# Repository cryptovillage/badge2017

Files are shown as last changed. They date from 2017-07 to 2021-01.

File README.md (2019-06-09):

# badge2017

To buld the ESP32 firmware:

1. Install the ESP32 toolchain for your OS. You do not need to install the ESP-IDF -- that happens automatically in the$
  * For Linux: https://esp-idf.readthedocs.io/en/v3.1-beta1/get-started/linux-setup.html
  * For Windows: https://esp-idf.readthedocs.io/en/v3.1-beta1/get-started/windows-setup.html
  * For OSX: https://esp-idf.readthedocs.io/en/v3.1-beta1/get-started/macos-setup.html

2. Pull in the ESP-IDF, MicroPython, and other dependencies:
`git submodule update --init --recursive`

3. Build mpy_cross:
`cd firmware/esp32/components/micropython/micropython/mpy-cross/ && make && cd ../../../..`

4. Optionally configure the serial port that your badge appears on (under Serial Flasher Config):
`make menuconfig`

5. Build it:
`make -j5`

6. Flash it:
`make flash` OR

`python esptool/esptool.py --chip esp32 --port /dev/ttyUSB0 --baud 115200 --before default_reset --after hard_reset write_flash -z --flash_mode dio --flash_freq 40m --flash_size detect 0x1000 bootloader.bin 0x10000 cpv2017.bin 0x8000 partitions.bin`

you may need to replace /dev/ttyUSB0 with /dev/ttyACM0 or whatever serial device the badge is listed as.

You can edit the build configuration with (includes wifi creds):

`make menuconfig`

SD Card contents can be found: https://2017.badge.cryptovillage.org/sdcard/0.3-prerel.zip

If your device is showing "TEST MODE", the EFM8 needs to be flashed. We've found that this only works from a Windows computer or Virtualbox with the Extension Pack for USB devices. If using a VM, we found that the IE11 Win7 testing VM from MicroSoft worked. You will need to install the driver from: https://www.silabs.com/products/development-tools/software/usb-to-uart-bridge-vcp-drivers

Download the flashing tools here: https://2017.badge.cryptovillage.org/W18779AXC7/TestFlash.zip

The prebuilt firmware can be found here: https://2017.badge.cryptovillage.org/firmware/v0.9/

You need to replace esp32test.bin with cpv2017.bin, and partitions_singleapp.bin with partitions.bin in TestFlash after unzipping. (Keeping the original filenames from TestFlash.zip contents but replacing the file content)

Hold down the knob when plugging the device in to put the device into a mode to flash the EFM8. The LEDs should not turn on and the screen will be blank and dim.

Run efm8load.exe to flash the EFM8. The device should reboot, but may require replugging in the USB cable. It should now appear as a serial device.

Then run NodeMCU-PyFlasher.exe to flash the ESP32.

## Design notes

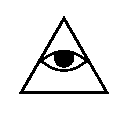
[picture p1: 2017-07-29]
assets/images/triangleeye.png

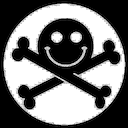
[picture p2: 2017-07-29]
assets/images/defcon.png

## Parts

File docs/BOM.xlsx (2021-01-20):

Item | Qty | Part Type | Reference | Manufacturer | Manufacturer P/N | Supplier | Supplier P/N | Description | Unit Price | Total | Link
1 | 1 | Rotary Encoder | SW1 | TT Electronics/BI | EN12-HS22AF20 | Digikey | 987-1195-ND | ENCODER 12MM ROTARY SW TOP ADJ | $0.67 | $0.67 | https://www.digikey.com/product-detail/en/tt-electronics-bi/EN12-HS22AF20/987-1195-ND/2408773
2 | 8 | LEDs | LED1,LED2,LED3,LED4,LED5,LED6,LED7,LED8 | Shenzhen Witop technology Company Co,.Ltd | APA-102-2020 |  |  | DOTSTAR MICRO LED APA102-2020 | $0.18 | $1.44 | https://www.digikey.com/products/en/optoelectronics/addressable-specialty/126?k=APA102%E2%80%932020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
3 | 1 | Screen |  | EastRising | ERC12864FS-1 | BuyDisplays.com | ERC12864FS-1 | 1.4 inch Graphic 128x64 LCD Module Serial SPI ST7565 Black on White | $2.84 | $2.84 | http://www.buydisplay.com/default/1-4-inch-graphic-128x64-lcd-module-serial-spi-st7565-black-on-white
4 | 1 | Screen connector | P5 | EastRising | ER-CON30HB-1 | BuyDisplays.com |  | 30 Pins 0.50mm Pitch ZIF Connector for Display | $0.16 | $0.16 | http://www.buydisplay.com/default/1-4-inch-graphic-128x64-lcd-module-serial-spi-st7565-black-on-white
5 | 1 | Screen connector | P6 | EastRising | ER-CON2.0-2P-SMD | BuyDisplays.com |  | 2 Pins 2.00mm Pitch Backlight Connector | $0.15 | $0.15 | http://www.buydisplay.com/default/1-4-inch-graphic-128x64-lcd-module-serial-spi-st7565-black-on-white
6 | 1 | LiPo Connector (2.00mm) | P3 | JST Sales America Inc. | S2B-PH-SM4-TB(LF)(SN) | Digikey | 455-1749-1-ND | 2 Positions Header, Shrouded Connector 0.079" (2.00mm) Surface Mount, Right Angle Tin | $0.42 | $0.42 | https://www.digikey.com/products/en?keywords=455-1749-1-ND
7 | 1 | LiPo |  |  |  |  |  | ~2300Mah |  | $0.00
8 | 1 | Micro USB Connector | P1 | Amphenol | 10118192-0001LF | Digikey | 609-4613-1-ND | USB - micro B USB 2.0 Receptacle Connector 5 Position Surface Mount, Right Angle, Horizontal | $0.27 | $0.27 | https://www.digikey.com/products/en?keywords=609-4613-1-ND
9 | 1 | ESP32 | U7 | Espressif | Espressif | Espressif | ESP-WROOM-32 | ESP32 module | $3.00 | $3.00 | https://espressif.com/en/products/hardware/esp32/overview
10 | 1 | MicroSD Holder | CON1 | Molex, LLC | 472192001 | Digikey | WM6698CT-ND | CONN MICRO SD CARD HINGED TYPE | $0.76 | $0.76 | https://www.digikey.com/product-detail/en/molex-llc/0472192001/WM6698CT-ND/3044147
11 | 1 | MicroSD Card |  |  |  |  |  | 4GB | $3.40 | $3.40 | https://www.aliexpress.com/item/Hot-sale-Memory-Cards-Micro-SD-Card-2GB-4GB-32GB-class-10-class-6-Microsd-TF/32700294360.html
12 | 1 | Resistor | R14 |  |  |  |  | 15 ohm, 10%, 1/10W, 0603 |  | $0.00
13 | 10 | Resistor | R1,R6,R9,R10,R11,R31,R41,R48,R49,R50 |  |  |  |  | 1k ohm, 5%, 0603 |  | $0.00
14 | 1 | Resistor | R8 |  |  |  |  | 1k87 ohm, 2%, 0603 |  | $0.00
15 | 1 | Resistor | R23 |  |  |  |  | 2k ohm, 5% 0603 |  | $0.00
16 | 1 | Resistor | R35 |  |  |  |  | 2k2 ohm, 5% 0603 |  | $0.00
17 | 2 | Resistor | R2,R3 |  |  |  |  | 4k7 ohm, 10%, 0603 |  | $0.00
18 | 1 | Resistor | R7 |  |  |  |  | 5k62 ohm, 2%, 0603 |  | $0.00
19 | 8 | Resistor | R21,R42,R43,R44,R45,R46,R47 |  |  |  |  | 10k ohm, 5%, 0603 |  | $0.00
20 | 1 | Resistor | R33 |  |  |  |  | 20k ohm, 5%, 0603 |  | $0.00
21 | 2 | Resistor | R27,R28 |  |  |  |  | 22k ohm, 5%, 0603 |  | $0.00
22 | 2 | Resistor | R29,R30 |  |  |  |  | 47k ohm, 5%, 0603 |  | $0.00
23 | 9 | Resistor | R4,R5,R13,R20,R22,R34,R37,R39,R40 |  |  |  |  | 100k ohm, 5%, 0603 |  | $0.00
24 | 1 | Resistor | R38 |  |  |  |  | 160k ohm, 5%, 0603 |  | $0.00
25 | 1 | Resistor | R36 |  |  |  |  | 200k ohm, 5%, 0603 |  | $0.00
26 | 1 | Resistor | R32 |  |  |  |  | 330k ohm, 5%, 0603 |  | $0.00
27 | 2 | Capacitor | C9,C10 |  |  |  |  | 12.5pF, +/-10%, 6.3V, 0603 |  | $0.00
28 | 1 | Capacitor | C48 |  |  |  |  | 47pF, +/- 10%, 6.3V, NP0/C0G, 0603 | 0.0098 | $0.01
29 | 1 | Capacitor | C46 |  |  |  |  | 0.01uF, +/- 10%, 6.3V, 0603 |  | $0.00
30 | 9 | Capacitor | C2,C8,C11,C16,C33,C34,C41,C42,C45 |  |  |  |  | 0.1uF, +/- 10%, 6.3V, NP0/COG, 0603 |  | $0.00
31 | 2 | Capacitor | C36,C37 |  |  |  |  | 0.47uF, +/- 10%, 6.3V, NP0/C0G, 0603 | 0.01372 | $0.03
32 | 21 | Capacitor | C6,C18,C19,C20,C21,C22,C23,C24,C25,C26,C27,C28,C29,C30,C31,C32,C38,C39,C40,C43,C44 |  |  |  |  | 1uF, +/- 20%, 25V, X5R/X7R, 0603 | 0.00796 | $0.17
33 | 5 | Capacitor | C1,C3,C4,C5,C35 |  |  |  |  | 4.7uF, +/- 20%, 16V, X5R/X7R, 0603 | 0.0266 | $0.13
34 | 5 | Capacitor | C7,C12,C13,C17,C47 |  |  |  |  | 10uF, +/- 20%, 16V, X5R/X7R, 0603 | 0.0404 | $0.20
35 | 2 | Capacitor | C14,C15 | Yageo |  |  |  | 22uF, +/- 20%, 10V, X5R/X7R, 0603 | 0.07176 | $0.14
36 | 1 | Resettable Fuse | F1 | Bourns Inc. | MF-USMF110-2 | Digikey | MF-USMF110-2CT-ND | 1100mA, 6V, 1210 | 0.2112 | $0.21
37 | 1 | Mic amp | U11 | Maxim Integrated | MAX4468EKA+T | Digikey | MAX4468EKA+CT-ND | IC PREAMP AUDIO MONO AB SOT23-8 | $0.51 | $0.51
38 | 1 | Headphone amp | U10 | Maxim Integrated | MAX9723DETE+ | Digikey | MAX9723DETE+-ND | IC AMP AUDIO .06W STER AB 16TQFN | $0.78 | $0.78
39 | 1 | Accelerometer | U9 | NXP | MMA8452QT | Digikey | MMA8452QT-ND | ACCELEROMETER 2-8G I2C 16QFN | $1.02 | $1.02
40 | 1 | switch | SW2 | C&K Components | JS202011SCQN | Digikey | 401-2002-1-ND | SWITCH SLIDE DPDT 300MA 6V | $0.36 | $0.36 | https://www.digikey.com/products/en?keywords=401-2002-1-ND
41 | 1 | crystal (32.768kHz) | Y1 | Abracon LLC | ABS25-32.768KHZ-T | Digikey | 535-9166-1-ND | CRYSTAL 32.7680KHZ 12.5PF SMD | $0.26 | $0.26 | https://www.digikey.com/product-detail/en/abracon-llc/ABS25-32.768KHZ-T/535-9166-1-ND/675683
42 | 2 | inductor | L1,L2 | Murata Electronics North America | LQM21PN4R7MGSD | Digikey | 490-12067-1-ND | 4.7 micro henry 750mA Inductor | $0.07 | $0.14 | http://www.digikey.com/product-detail/en/murata-electronics-north-america/LQM21PN4R7MGSD/490-12067-1-ND/5403080
43 | 2 | schottky diodes | D1,D2 | STMicroelectronics | BAT20JFILM | Digikey | 497-3381-1-ND | DIODE SCHOTTKY 23V 1A SOD323 | $0.21 | $0.41 | https://www.digikey.com/products/en?keywords=497-3381-1-ND
44 | 1 | microcontroller | U3 | Silicon Labs | EFM8UB10F16G-C-QFN28 | Digikey | 336-3409-5-ND | IC MCU 8BIT 16KB FLASH 28QFN | $1.22 | $1.22
45 | 1 | PMOS transistor | Q1 | Diodes Incorporated | DMG2307L-7 | Digikey | DMG2307L-7DICT-ND | MOSFET P-CH 30V 2.5A SOT-23 | $0.18 | $0.18
46 | 5 | NMOS transistor | Q2,Q3,Q4,Q5,Q6 | Fairchild/ON Semiconductor | MMBF170 | Digikey | MMBF170CT-ND | MOSFET N-CH 60V 500MA SOT-23 | $0.18 | $0.88 | https://www.digikey.com/products/en?keywords=DMG2307L-7DICT-ND
47 | 1 | Level Shifter | U8 | NXP USA Inc. | 74HCT245PW,118 | Digikey | 568-8174-1-ND | IC TRANSCVR TRI-ST 8BIT 20TSSOP | $0.25 | $0.25 | https://www.digikey.com/products/en?keywords=568-8174-1-ND
48 | 1 | ESD Protection Diode | U1 | Littelfuse Inc. | SP0503BAHTG | Digikey | F2715CT-ND | TVS DIODE 5.5VWM 8.5VC SOT143 | $0.59 | $0.59 | https://www.digikey.com/product-detail/en/littelfuse-inc/SP0503BAHTG/F2715CT-ND/1154322
49 | 1 | Battery Charger IC | U2 | Microchip | MCP73831T-2ACI/OT | Digikey | MCP73831T-2ACI/OTCT-ND | IC CONTROLLR LI-ION 4.2V SOT23-5 | $0.43 | $0.43 | https://www.digikey.com/products/en?keywords=MCP73831T-2ACI%2FOTCT-ND
50 | 1 | 3.3v Regulator | U6 | Diodes Incorporated | PAM2305AAB330 | Digikey | PAM2305AAB330DIDKR-ND | IC REG BUCK 3.3V 1A SYNC TSOT25 | $0.36 | $0.36 | https://www.digikey.com/products/en?keywords=PAM2301CAAB330DICT-ND
51 | 1 | 5v Regulator | U5 | Microchip Technology | MIC2288YD5-TR | Digikey | 576-1729-1-ND | IC REG BOOST ADJ 1.2A TSOT23-5 | $0.42 | $0.42 | https://www.digikey.com/product-detail/en/microchip-technology/MIC2288YD5-TR/576-1729-1-ND/1799425
52 | 1 | Crypto Chip | U4 | Atmel | ATECC508A-SSHDA-B | Digikey | ATECC508A-SSHDA-B-ND | IC EEPROM CRYPTO 10KB I2C 8SOIC | $0.66 | $0.66 | https://www.digikey.com/products/en?keywords=ATECC508A-SSHDA-B-ND
53 | 1 | TRRS 3.5mm jack | CON2 | CUI, Inc | SJ-43516-SMT-TR | Digikey | CP-43516SJCT-ND | 3.50mm (0.141", 1/8", Mini Plug) - Headphone Jack | $0.82 | $0.82 | http://www.digikey.com/product-detail/en/cui-inc/SJ-43516-SMT-TR/CP-43516SJCT-ND/669731
54 | 1 | PCB |  | PCBWay |  |  |  | 154.5mm x 95.1mm x 1.6mm, 2 Layers, 1 oz cu, Matte black soldermask, ENIG finish | $1.78 | $1.78
55 | 1 | Anti-static Bag | N/A | SCS | 10057 | Digikey | SCP390-ND | BAG 5X7" STATIC SHIELD 1=1EA | $0.10 | $0.10 | https://www.digikey.com/product-detail/en/scs/10057/SCP390-ND/3430431
56 | 1 | Lanyard | N/A | Custom Lanyards 4 All | N/A | Custom Lanyards 4 All |  | Polyester or Dye Sub? | $1.68 or $1.37 | $1.68 | https://www.customlanyards4all.com/
57 | 1 | Box | N/A |  |  | Alibaba |  | Black magnetic box (20cm x 14cm x 5cm) | $1.50 | $1.50
58 | 1 | USB Cable | N/A |  |  | Monoprice |  | USB 2.0 to Micro (black) | $0.61 | $0.61 | https://www.monoprice.com/product?c_id=103&cp_id=10303&cs_id=1030307&p_id=5137&seq=1&format=2
59 | 1 | Headphones | N/A | ??? | #04976961 | Light in the Box | N/A | N/A | $1.19 | $1.19 | http://www.lightinthebox.com/3-5mm-in-ear-headphones-headset-earphones-for-samsung-pc-cellphone_p4499380.html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
60 | 1 | Knob | N/A
61 | 1 | Instruction Sheet | N/A
 |  |  |  |  |  |  |  |  |  | $30.17

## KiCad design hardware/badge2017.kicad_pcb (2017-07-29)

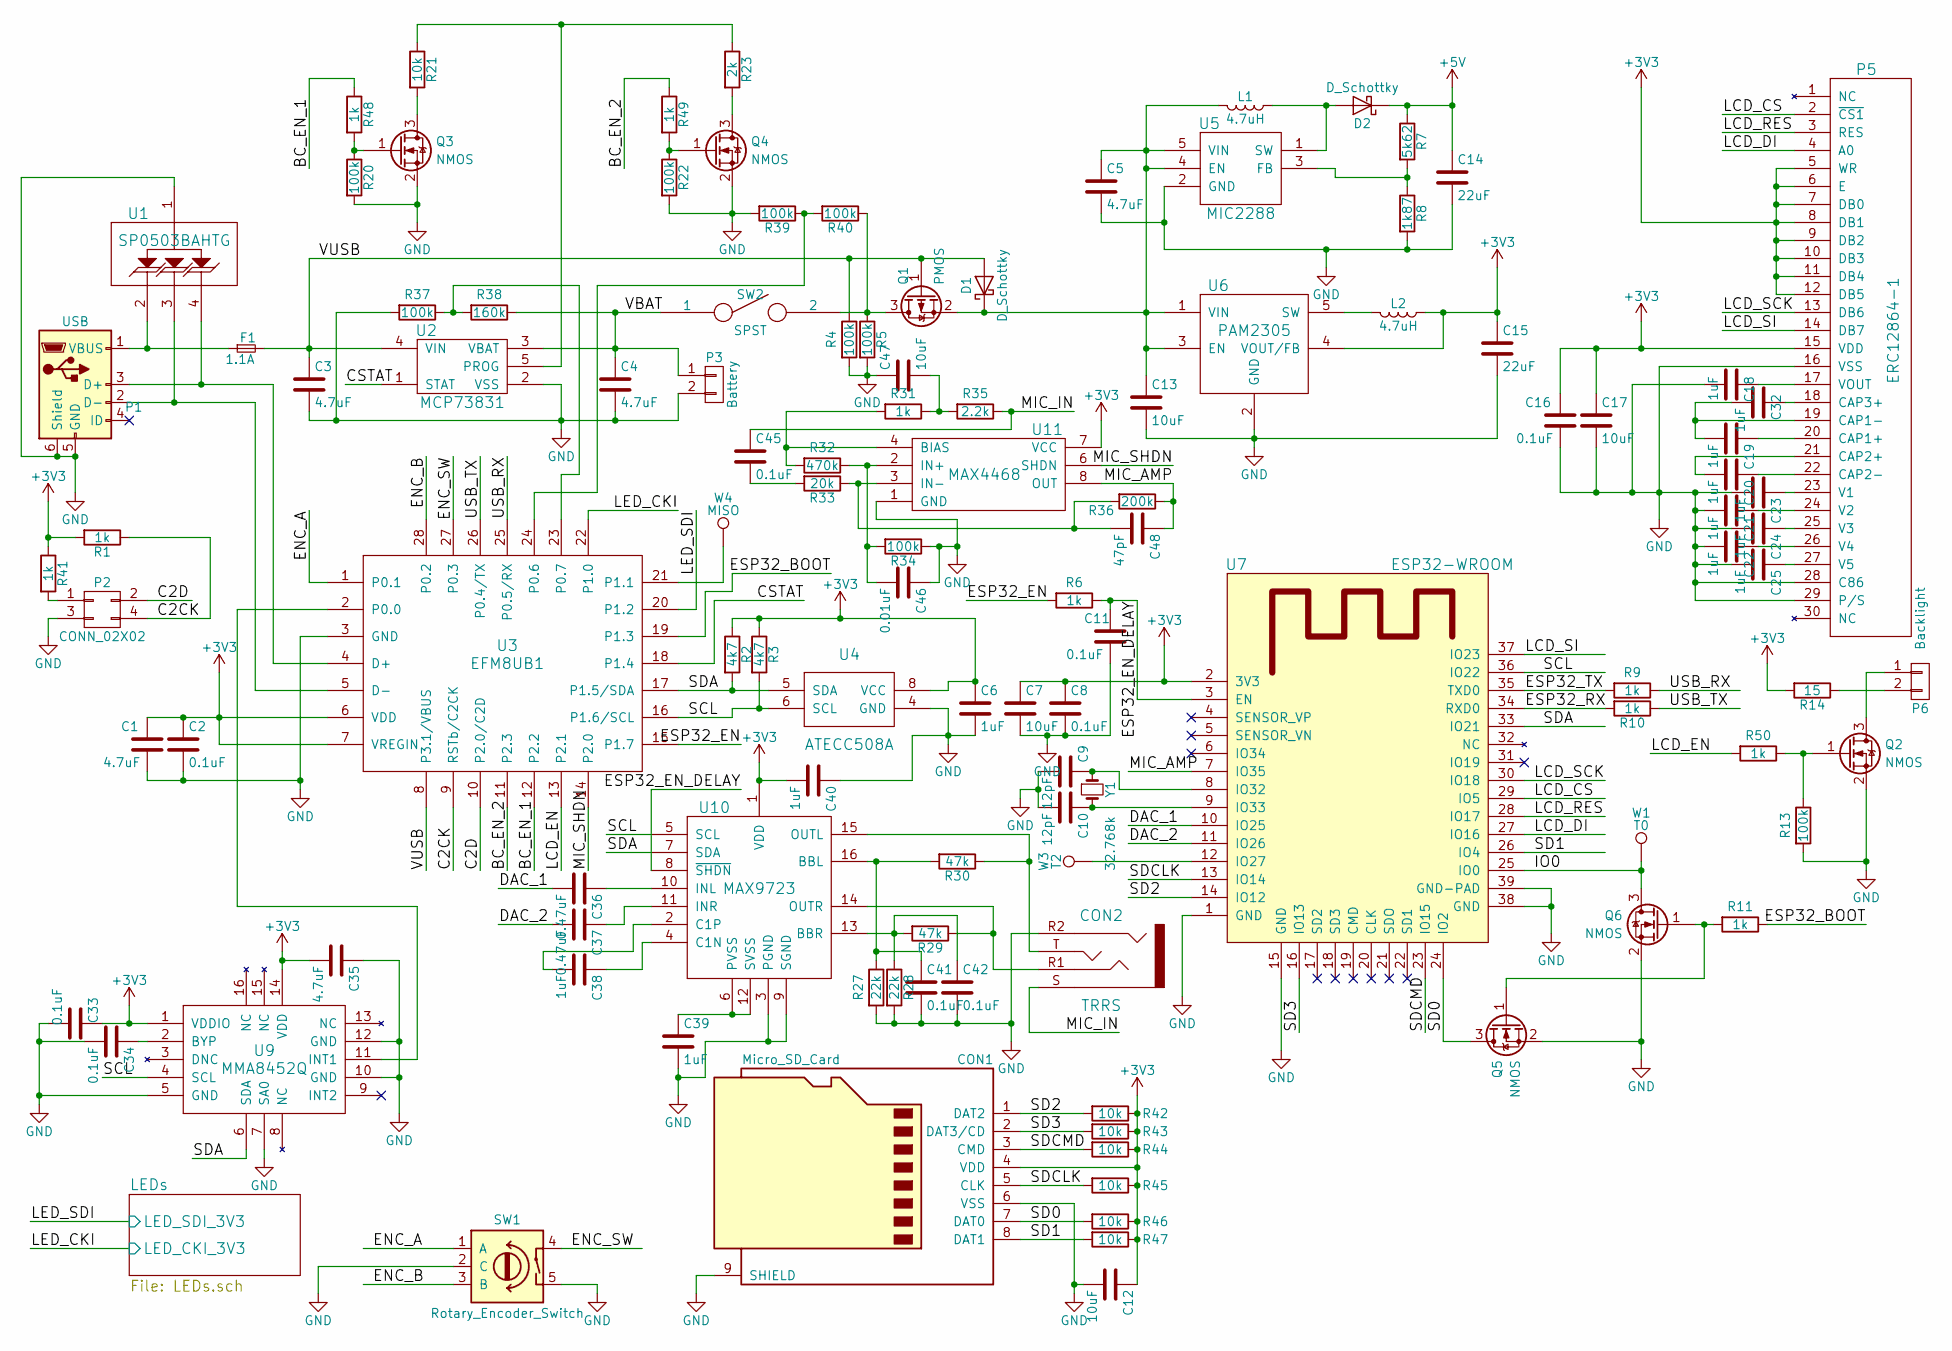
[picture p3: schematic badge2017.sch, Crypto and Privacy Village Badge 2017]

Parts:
C1, C35: 4.7uF; C_0603; Tolerance +/- 20%; Voltage 6.3V
C2, C8, C11, C16, C33, C34: 0.1uF; C_0603; Tolerance +/- 20%; Voltage 6.3V
C3, C4, C5: 4.7uF; C_0603; Tolerance +/- 20%; Voltage 16V
C6, C38, C40: 1uF; C_0603; Tolerance +/- 20%; Voltage 6.3V
C7, C12, C17, C47: 10uF; C_0603; Tolerance +/- 20%; Voltage 6.3V
C9, C10: 12pF; C_0603; Tolerance +/- 10%; Voltage 6.3V
C13: 10uF; C_0603; Tolerance +/- 20%; Voltage 16V
C14, C15: 22uF; C_0603; Tolerance +/- 20%; Voltage 10V
C18, C19, C20, C21, C22, C23, C24, C25, C32: 1uF; C_0603; Tolerance +/- 20%; Voltage 25V
C36, C37: 0.47uF; C_0603; Tolerance +/- 10%; Voltage 6.3V
C39: 1uF; C_0603; Tolerance +/- 20%; Voltage 16V
C41, C42, C45: 0.1uF; C_0603; Tolerance +/- 10%; Voltage 6.3V
C46: 0.01uF; C_0603; Tolerance +/- 10%; Voltage 6.3V
C48: 47pF; C_0603; Tolerance +/- 10%; Voltage 6.3V
CON1: Micro_SD_Card; MICROSD; MfgPartNum 472192001
CON2: TRRS; TRRS_jack; MfgPartNum SJ-43516-SMT-TR
D1, D2: D_Schottky; SOD-323; MfgPartNum BAT20JFILM
F1: 1.1A; R_1210; MfgPartNum MF-USMF110-2
L1, L2: 4.7uH; R_0603; MfgPartNum LQM21PN4R7MGSD
P1: USB; USB_Micro-B-cpv; MfgPartNum 10118192-0001LF
P2: CONN_02X02; Socket_Strip_Straight_2x02_TP
P3: Battery; JST_PH_SMD
P5: ERC12864-1; LCD_zif_connector
P6: Backlight; JST_PH_SMD
Q1: PMOS; SOT-23; MfgPartNum DMG2307L-7
Q2, Q3, Q4, Q5, Q6: NMOS; SOT-23; MfgPartNum MMBF170
R1, R6, R9, R10, R11, R41, R48, R49, R50: 1k; R_0603
R2, R3: 4k7; R_0603; Tolerance 0.1
R4, R5, R13, R20, R22: 100k; R_0603
R7: 5k62; R_0603; Tolerance 0.02
R8: 1k87; R_0603; Tolerance 0.02
R14: 15; R_0603; Tolerance 0.1
R21: 10k; R_0603; Tolerance 0.05
R23: 2k; R_0603; Tolerance 0.05
R27, R28: 22k; R_0603; Tolerance 0.05
R29, R30: 47k; R_0603; Tolerance 0.05
R31: 1k; R_0603; Tolerance 0.05
R32: 470k; R_0603; Tolerance 0.05
R33: 20k; R_0603; Tolerance 0.05
R34, R37, R39, R40: 100k; R_0603; Tolerance 0.05
R35: 2.2k; R_0603; Tolerance 0.05
R36: 200k; R_0603; Tolerance 0.05
R38: 160k; R_0603; Tolerance 0.05
R42, R43, R44, R45, R46, R47: 10k; R_0603
SW1: Rotary_Encoder_Switch; EN12_RotaryEncoder; MfgPartNum EN12-HS22AF20
SW2: SPST; DPDT_SMD; MfgPartNum JS202011SCQN
U1: SP0503BAHTG; SOT-143; MfgPartNum SP0503BAHTG
U2: MCP73831; SOT-23-5; MfgPartNum MCP73831T-2ACI/OT
U3: EFM8UB1; QFN-28-1EP_5x5mm_Pitch0.5mm; MfgPartNum EFM8UB10F16G-C-QFN28
U4: ATECC508A; SOIC-8_3.9x4.9mm_Pitch1.27mm; MfgPartNum ATECC508A-SSHDA-B
U5: MIC2288; SOT-23-5; MfgPartNum MIC2288YD5-TR
U6: PAM2305; SOT-23-5; MfgPartNum PAM2305AAB330
U7: ESP32-WROOM; MfgPartNum ESP-WROOM-32
U9: MMA8452Q; MfgPartNum MMA8452QT
U10: MAX9723; QFN-16-1EP_4x4mm_Pitch0.65mm; MfgPartNum MAX9723DETE+
U11: MAX4468; SOT-23-8; MfgPartNum MAX4468EKA+T
W1: T0; Measurement_Point_Round-SMD-Pad_Small
W3: T2; Measurement_Point_Round-SMD-Pad_Small
W4: MISO; Measurement_Point_Round-SMD-Pad_Small
Y1: 32.768k; abs25_crystal; MfgPartNum ABS25-32.768KHZ-T

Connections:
+3V3: C1.1, C2.1, C6.1, C7.1, C8.1, C12.1, C15.1, C16.1, C17.1, C33.1, C35.2, C40.2, CON1.4 (VDD), L2.1, P5.5 (WR), P5.6 (E), P5.7 (DB0), P5.8 (DB1), P5.9 (DB2), P5.10 (DB3), P5.11 (DB4), P5.12 (DB5), P5.15 (VDD), R1.2, R2.1, R3.1, R14.2, R41.1, R42.1, R43.1, R44.1, R45.1, R46.1, R47.1, U3.6 (VDD), U3.7 (VREGIN), U4.8 (VCC), U6.4 (VOUT/FB), U7.2 (3V3), U9.1 (VDDIO), U9.14 (VDD), U10.1 (VDD), U11.7 (VCC)
+5V: C14.1, D2.1 (K), R7.1; also elsewhere on the board
/BC_EN_1: R48.1, U3.12 (P2.2)
/BC_EN_2: R49.1, U3.11 (P2.3)
/C2CK: P2.4, R1.1, U3.9 (RSTb/C2CK)
/C2D: P2.2, U3.10 (P2.0/C2D)
/CSTAT: U2.1 (STAT), U3.18 (P1.4)
/DAC_1: C36.2, U7.10 (IO25)
/DAC_2: C37.2, U7.11 (IO26)
/ENC_A: SW1.1 (A), U3.1 (P0.1)
/ENC_B: SW1.3 (B), U3.28 (P0.2)
/ENC_SW: SW1.4, U3.27 (P0.3)
/ESP32_BOOT: R11.1, U3.19 (P1.3)
/ESP32_EN: R6.2, U3.15 (P1.7)
/ESP32_EN_DELAY: C11.1, R6.1, U7.3 (EN), U10.8 (~SHDN)
/ESP32_RX: R10.2, U7.34 (RXD0)
/ESP32_TX: R9.2, U7.35 (TXD0)
/IO0: Q6.3 (D), U7.25 (IO0), W1.1
/LCD_CS: P5.2 (~CS1), U7.29 (IO5)
/LCD_DI: P5.4 (A0), U7.27 (IO16)
/LCD_EN: R50.2, U3.13 (P2.1)
/LCD_RES: P5.3 (RES), U7.28 (IO17)
/LCD_SCK: P5.13 (DB6), U7.30 (IO18)
/LCD_SI: P5.14 (DB7), U7.37 (IO23)
/LED_CKI: U3.22 (P1.0); also elsewhere on the board
/LED_SDI: U3.20 (P1.2); also elsewhere on the board
/MIC_AMP: C48.1, R36.1, U7.7 (IO35), U11.8 (OUT)
/MIC_IN: C45.1, CON2.S, R35.1
/MIC_SHDN: U3.14 (P2.0), U11.6 (SHDN)
/SCL: R3.2, U3.16 (P1.6/SCL), U4.6 (SCL), U7.36 (IO22), U9.4 (SCL), U10.5 (SCL)
/SD0: CON1.7 (DAT0), Q5.3 (D), R46.2, U7.24 (IO2)
/SD1: CON1.8 (DAT1), R47.2, U7.26 (IO4)
/SD2: CON1.1 (DAT2), R42.2, U7.14 (IO12)
/SD3: CON1.2 (DAT3/CD), R43.2, U7.16 (IO13)
/SDA: R2.2, U3.17 (P1.5/SDA), U4.5 (SDA), U7.33 (IO21), U9.6 (SDA), U10.7 (SDA)
/SDCLK: CON1.5 (CLK), R45.2, U7.13 (IO14)
/SDCMD: CON1.3 (CMD), R44.2, U7.23 (IO15)
/USB_RX: R9.1, U3.25 (P0.5/RX)
/USB_TX: R10.1, U3.26 (P0.4/TX)
/VBAT: C4.1, P3.1, R38.1, SW2.1, U2.3 (VBAT)
/VUSB: C3.1, D1.2 (A), F1.2, Q1.1 (G), R4.1, U2.4 (VIN), U3.8 (P3.1/VBUS)
GND: C1.2, C2.2, C3.2, C4.2, C5.2, C6.2, C7.2, C8.2, C9.2, C10.2, C11.2, C12.2, C13.2, C14.2, C15.2, C16.2, C17.2, C18.2, C21.2, C22.2, C23.2, C24.2, C25.2, C33.2, C34.2, C35.1, C39.2, C40.1, C41.2, C42.2, C46.1, C47.1, CON1.6 (VSS), CON1.9 (SHIELD), CON2.R2, P1.5 (GND), P1.6 (Shield), P2.3, P3.2, P5.16 (VSS), P5.28 (C86), P5.29 (P/S), Q2.2 (S), Q3.2 (S), Q4.2 (S), Q5.2 (S), Q6.2 (S), R4.2, R5.2, R8.2, R13.2, R20.2, R22.2, R27.2, R28.2, R34.1, R37.2, R39.2, SW1.2 (C), SW1.5, U1.1, U2.2 (VSS), U3.3 (GND), U4.4 (GND), U5.2 (GND), U6.2 (GND), U7.1 (GND), U7.15 (GND), U7.38 (GND), U7.39 (GND-PAD), U9.5 (GND), U9.7 (SA0), U9.10 (GND), U9.12 (GND), U10.3 (PGND), U10.9 (SGND), U11.1 (GND); also elsewhere on the board
unnamed: C9.1, U7.8 (IO32), Y1.1
unnamed: C10.1, U7.9 (IO33), Y1.2
unnamed: C5.1, C13.1, D1.1 (K), L1.2, Q1.2 (S), U5.4 (EN), U5.5 (VIN), U6.1 (VIN), U6.3 (EN)
unnamed: C18.1, P5.17 (VOUT)
unnamed: C19.1, P5.20 (CAP1+)
unnamed: C19.2, C32.2, P5.19 (CAP1-)
unnamed: C20.1, P5.22 (CAP2-)
unnamed: C20.2, P5.21 (CAP2+)
unnamed: C21.1, P5.24 (V2)
unnamed: C22.1, P5.26 (V4)
unnamed: C23.1, P5.23 (V1)
unnamed: C24.1, P5.25 (V3)
unnamed: C25.1, P5.27 (V5)
unnamed: C32.1, P5.18 (CAP3+)
unnamed: C34.1, U9.2 (BYP)
unnamed: C36.1, U10.10 (INL)
unnamed: C37.1, U10.11 (INR)
unnamed: C38.1, U10.4 (C1N)
unnamed: C38.2, U10.2 (C1P)
unnamed: C39.1, U10.6 (PVSS), U10.12 (SVSS)
unnamed: C41.1, R27.1, R30.2, U10.16 (BBL)
unnamed: C42.1, R28.1, R29.2, U10.13 (BBR)
unnamed: C45.2, R33.2
unnamed: C46.2, R32.1, R34.2, U11.2 (IN+)
unnamed: C47.2, R31.1, R35.2
unnamed: C48.2, R33.1, R36.2, U11.3 (IN-)
unnamed: CON2.R1, R29.1, U10.14 (OUTR)
unnamed: CON2.T, R30.1, U10.15 (OUTL)
unnamed: D2.2 (A), L1.1, U5.1 (SW)
unnamed: F1.1, P1.1 (VBUS), U1.2
unnamed: L2.2, U6.5 (SW)
unnamed: P1.2 (D-), U1.3, U3.5 (D-)
unnamed: P1.3 (D+), U1.4, U3.4 (D+)
unnamed: P2.1, R41.2
unnamed: P6.1, Q2.3 (D)
unnamed: P6.2, R14.1
unnamed: Q1.3 (D), R5.1, R40.1, SW2.2
unnamed: Q2.1 (G), R13.1, R50.1
unnamed: Q3.1 (G), R20.1, R48.2
unnamed: Q3.3 (D), R21.2
unnamed: Q4.1 (G), R22.1, R49.2
unnamed: Q4.3 (D), R23.2
unnamed: Q5.1 (G), Q6.1 (G), R11.2
unnamed: R7.2, R8.1, U5.3 (FB)
unnamed: R21.1, R23.1, U2.5 (PROG)
unnamed: R31.2, R32.2, U11.4 (BIAS)
unnamed: R37.1, R38.2, U3.23 (P0.7)
unnamed: R39.1, R40.2, U3.24 (P0.6)
unnamed: U3.2 (P0.0), U9.11 (INT1)
unnamed: U3.21 (P1.1), W4.1
unnamed: U7.12 (IO27), W3.1

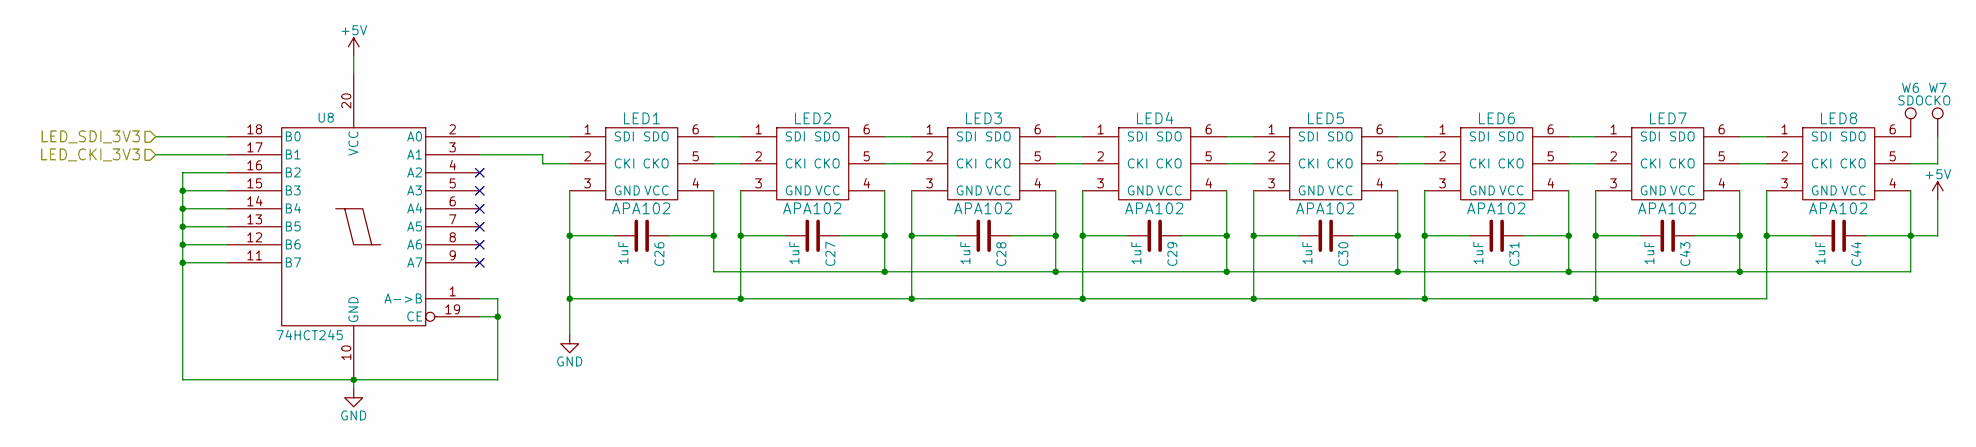
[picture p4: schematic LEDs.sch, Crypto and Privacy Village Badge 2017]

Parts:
C26, C27, C28, C29, C30, C31, C43, C44: 1uF; C_0603; Voltage 16V
LED1, LED2, LED3, LED4, LED5, LED6, LED7, LED8: APA102; APA102-2020
U8: 74HCT245; TSSOP-20_4.4x6.5mm_Pitch0.65mm; MfgPartNum 74HCT245PW,118
W6: SDO; Measurement_Point_Round-SMD-Pad_Small
W7: CKO; Measurement_Point_Round-SMD-Pad_Small

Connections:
+5V: C26.1, C27.1, C28.1, C29.1, C30.1, C31.1, C43.1, C44.1, LED1.4 (VCC), LED2.4 (VCC), LED3.4 (VCC), LED4.4 (VCC), LED5.4 (VCC), LED6.4 (VCC), LED7.4 (VCC), LED8.4 (VCC), U8.20 (VCC); also elsewhere on the board
/LED_CKI: U8.17 (B1); also elsewhere on the board
/LED_SDI: U8.18 (B0); also elsewhere on the board
GND: C26.2, C27.2, C28.2, C29.2, C30.2, C31.2, C43.2, C44.2, LED1.3 (GND), LED2.3 (GND), LED3.3 (GND), LED4.3 (GND), LED5.3 (GND), LED6.3 (GND), LED7.3 (GND), LED8.3 (GND), U8.1 (A->B), U8.10 (GND), U8.11 (B7), U8.12 (B6), U8.13 (B5), U8.14 (B4), U8.15 (B3), U8.16 (B2), U8.19 (CE); also elsewhere on the board
unnamed: LED1.1 (SDI), U8.2 (A0)
unnamed: LED1.2 (CKI), U8.3 (A1)
unnamed: LED1.5 (CKO), LED2.2 (CKI)
unnamed: LED1.6 (SDO), LED2.1 (SDI)
unnamed: LED2.5 (CKO), LED3.2 (CKI)
unnamed: LED2.6 (SDO), LED3.1 (SDI)
unnamed: LED3.5 (CKO), LED4.2 (CKI)
unnamed: LED3.6 (SDO), LED4.1 (SDI)
unnamed: LED4.5 (CKO), LED5.2 (CKI)
unnamed: LED4.6 (SDO), LED5.1 (SDI)
unnamed: LED5.5 (CKO), LED6.2 (CKI)
unnamed: LED5.6 (SDO), LED6.1 (SDI)
unnamed: LED6.5 (CKO), LED7.2 (CKI)
unnamed: LED6.6 (SDO), LED7.1 (SDI)
unnamed: LED7.5 (CKO), LED8.2 (CKI)
unnamed: LED7.6 (SDO), LED8.1 (SDI)
unnamed: LED8.5 (CKO), W7.1
unnamed: LED8.6 (SDO), W6.1

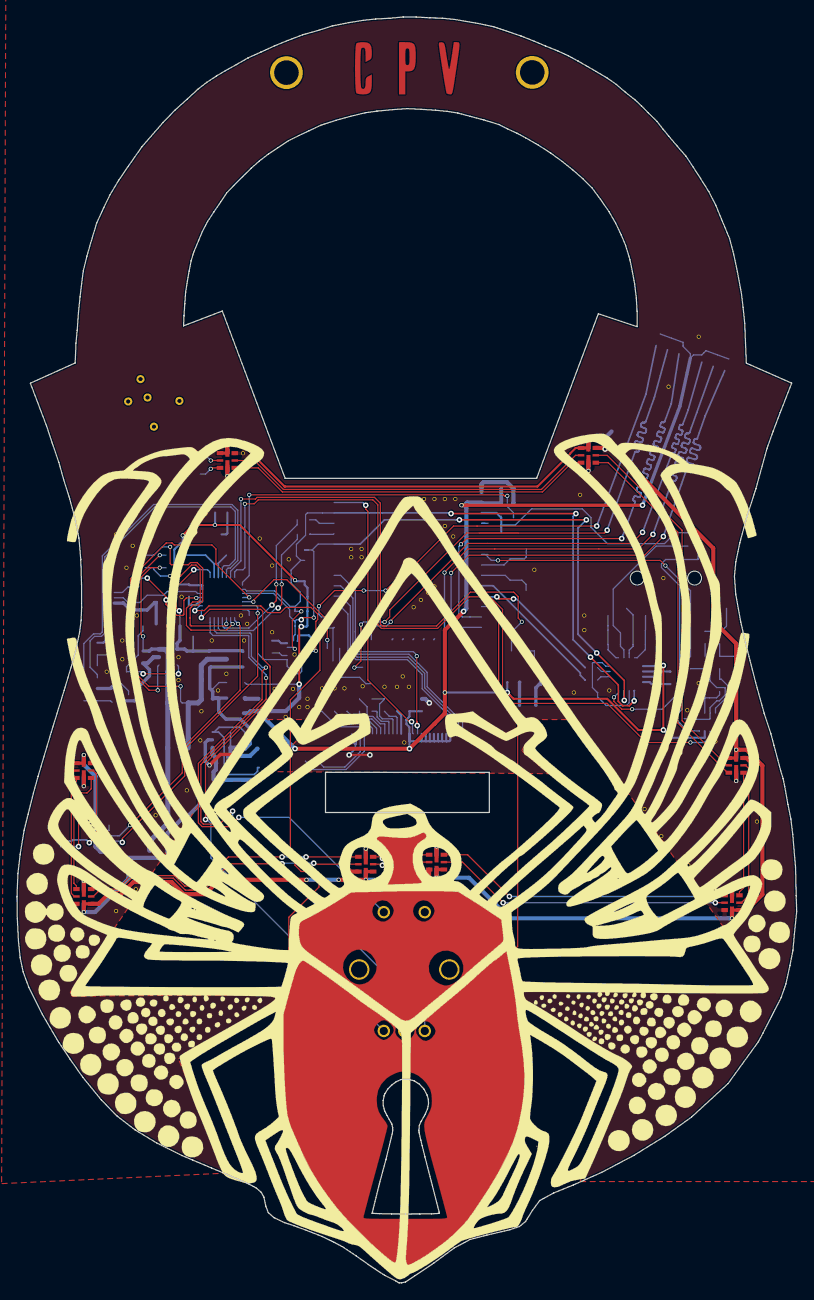
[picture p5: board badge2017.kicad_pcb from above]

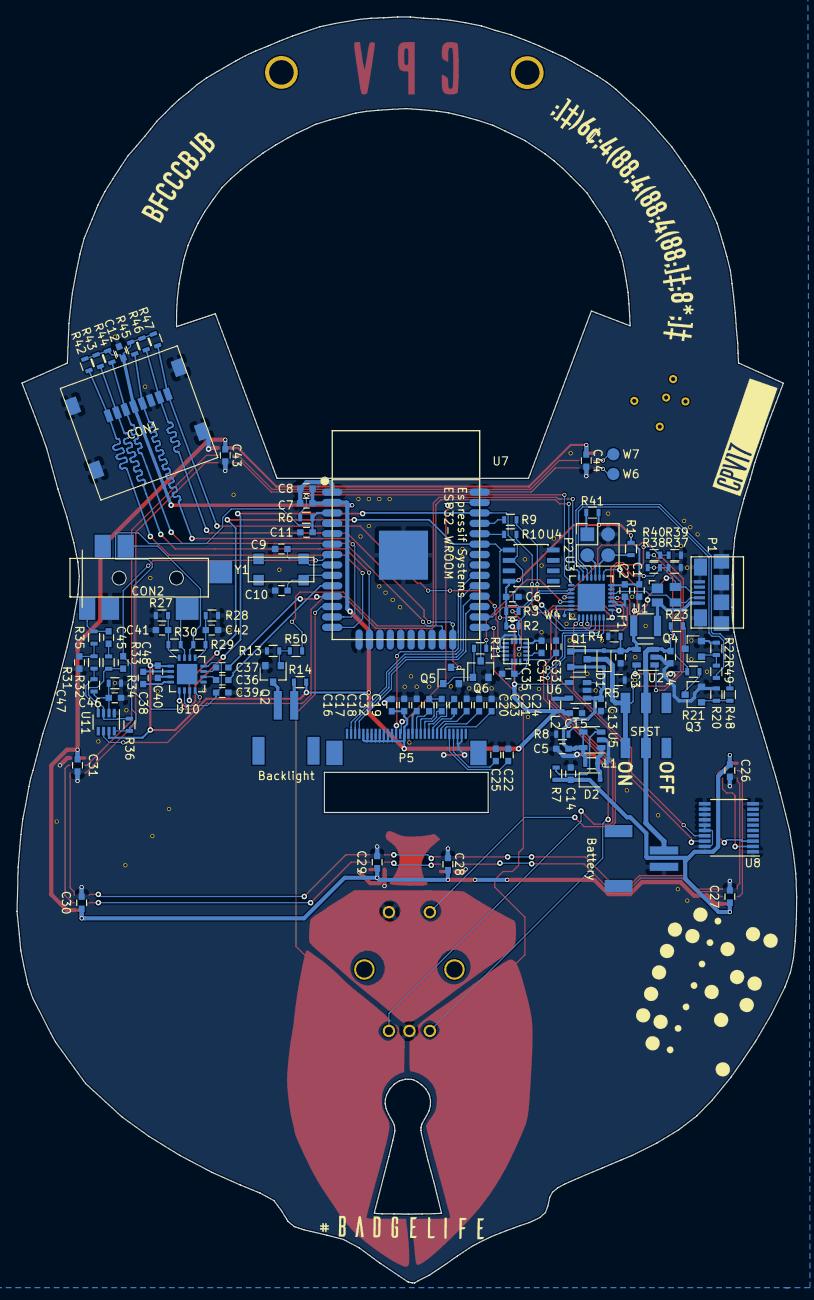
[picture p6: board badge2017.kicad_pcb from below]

Board: 2 copper layers, 95.2 x 154.5 mm, 138 parts (123 on the bottom side), 111 nets.

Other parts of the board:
LCD: LCD_outline
W2: T1; Measurement_Point_Round-SMD-Pad_Small
hole_l: hole
hole_l#2: hole

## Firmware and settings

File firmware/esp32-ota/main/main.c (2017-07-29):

/* HTTPS GET Example using plain mbedTLS sockets
 *
 * Contacts the howsmyssl.com API via TLS v1.2 and reads a JSON
 * response.
 *
 * Adapted from the ssl_client1 example in mbedtls.
 *
 * Original Copyright (C) 2006-2016, ARM Limited, All Rights Reserved, Apache 2.0 License.
 * Additions Copyright (C) Copyright 2015-2016 Espressif Systems (Shanghai) PTE LTD, Apache 2.0 License.
 *
 *
 * Licensed under the Apache License, Version 2.0 (the "License");
 * you may not use this file except in compliance with the License.
 * You may obtain a copy of the License at
 *
 *     http://www.apache.org/licenses/LICENSE-2.0
 *
 * Unless required by applicable law or agreed to in writing, software
 * distributed under the License is distributed on an "AS IS" BASIS,
 * WITHOUT WARRANTIES OR CONDITIONS OF ANY KIND, either express or implied.
 * See the License for the specific language governing permissions and
 * limitations under the License.
 */
#include <string.h>
#include <stdlib.h>
#include "freertos/FreeRTOS.h"
#include "freertos/task.h"
#include "freertos/event_groups.h"
#include "esp_wifi.h"
#include "esp_event_loop.h"
#include "esp_log.h"
#include "esp_system.h"
#include "nvs_flash.h"

#include "lwip/err.h"
#include "lwip/sockets.h"
#include "lwip/sys.h"
#include "lwip/netdb.h"
#include "lwip/dns.h"

#include "mbedtls/platform.h"
#include "mbedtls/net.h"
#include "mbedtls/esp_debug.h"
#include "mbedtls/ssl.h"
#include "mbedtls/entropy.h"
#include "mbedtls/ctr_drbg.h"
#include "mbedtls/error.h"
#include "mbedtls/certs.h"

/* The examples use simple WiFi configuration that you can set via
   'make menuconfig'.

   If you'd rather not, just change the below entries to strings with
   the config you want - ie #define EXAMPLE_WIFI_SSID "mywifissid"
*/
#define EXAMPLE_WIFI_SSID CONFIG_WIFI_SSID
#define EXAMPLE_WIFI_PASS CONFIG_WIFI_PASSWORD

/* FreeRTOS event group to signal when we are connected & ready to make a request */
static EventGroupHandle_t wifi_event_group;

/* The event group allows multiple bits for each event,
   but we only care about one event - are we connected
   to the AP with an IP? */
const int CONNECTED_BIT = BIT0;

/* Constants that aren't configurable in menuconfig */
#define WEB_SERVER "2017.badge.cryptovillage.org"
#define WEB_PORT "443"
#define WEB_URL "https://2017.badge.cryptovillage.org/ota"

static const char *TAG = "example";

static const char *REQUEST = "GET " WEB_URL " HTTP/1.0\r\n"
    "Host: "WEB_SERVER"\r\n"
    "User-Agent: esp-idf/1.0 esp32\r\n"
    "\r\n";

/* Root cert for howsmyssl.com, taken from server_root_cert.pem

   The PEM file was extracted from the output of this command:
   openssl s_client -showcerts -connect www.howsmyssl.com:443 </dev/null

   The CA root cert is the last cert given in the chain of certs.

   To embed it in the app binary, the PEM file is named
   in the component.mk COMPONENT_EMBED_TXTFILES variable.
*/
extern const uint8_t server_root_cert_pem_start[] asm("_binary_server_root_cert_pem_start");
extern const uint8_t server_root_cert_pem_end[]   asm("_binary_server_root_cert_pem_end");

static esp_err_t event_handler(void *ctx, system_event_t *event)
{
    switch(event->event_id) {
    case SYSTEM_EVENT_STA_START:
        esp_wifi_connect();
        break;
    case SYSTEM_EVENT_STA_GOT_IP:
        xEventGroupSetBits(wifi_event_group, CONNECTED_BIT);
        break;
    case SYSTEM_EVENT_STA_DISCONNECTED:
        /* This is a workaround as ESP32 WiFi libs don't currently
           auto-reassociate. */
        esp_wifi_connect();
        xEventGroupClearBits(wifi_event_group, CONNECTED_BIT);
        break;
    default:
        break;
    }
    return ESP_OK;
}

static void initialise_wifi(void)
{
    tcpip_adapter_init();
    wifi_event_group = xEventGroupCreate();
    ESP_ERROR_CHECK( esp_event_loop_init(event_handler, NULL) );
    wifi_init_config_t cfg = WIFI_INIT_CONFIG_DEFAULT();
    ESP_ERROR_CHECK( esp_wifi_init(&cfg) );
    ESP_ERROR_CHECK( esp_wifi_set_storage(WIFI_STORAGE_RAM) );
    wifi_config_t wifi_config = {
        .sta = {
            .ssid = EXAMPLE_WIFI_SSID,
            .password = EXAMPLE_WIFI_PASS,
        },
    };
    ESP_LOGI(TAG, "Setting WiFi configuration SSID %s...", wifi_config.sta.ssid);
    ESP_ERROR_CHECK( esp_wifi_set_mode(WIFI_MODE_STA) );
    ESP_ERROR_CHECK( esp_wifi_set_config(ESP_IF_WIFI_STA, &wifi_config) );
    ESP_ERROR_CHECK( esp_wifi_start() );
}

static void https_get_task(void *pvParameters)
{
    char buf[512];
    int ret, flags, len;

    mbedtls_entropy_context entropy;
    mbedtls_ctr_drbg_context ctr_drbg;
    mbedtls_ssl_context ssl;
    mbedtls_x509_crt cacert;
    mbedtls_ssl_config conf;
    mbedtls_net_context server_fd;

    mbedtls_ssl_init(&ssl);
    mbedtls_x509_crt_init(&cacert);
    mbedtls_ctr_drbg_init(&ctr_drbg);
    ESP_LOGI(TAG, "Seeding the random number generator");

    mbedtls_ssl_config_init(&conf);

    mbedtls_entropy_init(&entropy);
    if((ret = mbedtls_ctr_drbg_seed(&ctr_drbg, mbedtls_entropy_func, &entropy,
                                    NULL, 0)) != 0)
    {
        ESP_LOGE(TAG, "mbedtls_ctr_drbg_seed returned %d", ret);
        abort();
    }

    ESP_LOGI(TAG, "Loading the CA root certificate...");

    ret = mbedtls_x509_crt_parse(&cacert, server_root_cert_pem_start,
                                 server_root_cert_pem_end-server_root_cert_pem_start);

    if(ret < 0)
    {
        ESP_LOGE(TAG, "mbedtls_x509_crt_parse returned -0x%x\n\n", -ret);
        abort();
    }

    ESP_LOGI(TAG, "Setting hostname for TLS session...");

     /* Hostname set here should match CN in server certificate */
    if((ret = mbedtls_ssl_set_hostname(&ssl, WEB_SERVER)) != 0)
    {
        ESP_LOGE(TAG, "mbedtls_ssl_set_hostname returned -0x%x", -ret);
        abort();
    }

    ESP_LOGI(TAG, "Setting up the SSL/TLS structure...");

    if((ret = mbedtls_ssl_config_defaults(&conf,
                                          MBEDTLS_SSL_IS_CLIENT,
                                          MBEDTLS_SSL_TRANSPORT_STREAM,
                                          MBEDTLS_SSL_PRESET_DEFAULT)) != 0)
    {
        ESP_LOGE(TAG, "mbedtls_ssl_config_defaults returned %d", ret);
        goto exit;
    }

    /* MBEDTLS_SSL_VERIFY_OPTIONAL is bad for security, in this example it will print
       a warning if CA verification fails but it will continue to connect.

       You should consider using MBEDTLS_SSL_VERIFY_REQUIRED in your own code.
    */
    mbedtls_ssl_conf_authmode(&conf, MBEDTLS_SSL_VERIFY_OPTIONAL);
    mbedtls_ssl_conf_ca_chain(&conf, &cacert, NULL);
    mbedtls_ssl_conf_rng(&conf, mbedtls_ctr_drbg_random, &ctr_drbg);
#ifdef CONFIG_MBEDTLS_DEBUG
    mbedtls_esp_enable_debug_log(&conf, 4);
#endif

    if ((ret = mbedtls_ssl_setup(&ssl, &conf)) != 0)
    {
        ESP_LOGE(TAG, "mbedtls_ssl_setup returned -0x%x\n\n", -ret);
        goto exit;
    }

    while(1) {
        /* Wait for the callback to set the CONNECTED_BIT in the
           event group.
        */
        xEventGroupWaitBits(wifi_event_group, CONNECTED_BIT,
                            false, true, portMAX_DELAY);
        ESP_LOGI(TAG, "Connected to AP");

        mbedtls_net_init(&server_fd);

        ESP_LOGI(TAG, "Connecting to %s:%s...", WEB_SERVER, WEB_PORT);

        if ((ret = mbedtls_net_connect(&server_fd, WEB_SERVER,
                                      WEB_PORT, MBEDTLS_NET_PROTO_TCP)) != 0)
        {
            ESP_LOGE(TAG, "mbedtls_net_connect returned -%x", -ret);
            goto exit;
        }

        ESP_LOGI(TAG, "Connected.");

        mbedtls_ssl_set_bio(&ssl, &server_fd, mbedtls_net_send, mbedtls_net_recv, NULL);

        ESP_LOGI(TAG, "Performing the SSL/TLS handshake...");

        while ((ret = mbedtls_ssl_handshake(&ssl)) != 0)
        {
            if (ret != MBEDTLS_ERR_SSL_WANT_READ && ret != MBEDTLS_ERR_SSL_WANT_WRITE)
            {
                ESP_LOGE(TAG, "mbedtls_ssl_handshake returned -0x%x", -ret);
                goto exit;
            }
        }

        ESP_LOGI(TAG, "Verifying peer X.509 certificate...");

        if ((flags = mbedtls_ssl_get_verify_result(&ssl)) != 0)
        {
            /* In real life, we probably want to close connection if ret != 0 */
            ESP_LOGW(TAG, "Failed to verify peer certificate!");
            bzero(buf, sizeof(buf));
            mbedtls_x509_crt_verify_info(buf, sizeof(buf), "  ! ", flags);
            ESP_LOGW(TAG, "verification info: %s", buf);
        }
        else {
            ESP_LOGI(TAG, "Certificate verified.");
        }

        ESP_LOGI(TAG, "Writing HTTP request...");

        while((ret = mbedtls_ssl_write(&ssl, (const unsigned char *)REQUEST, strlen(REQUEST))) <= 0)
        {
            if(ret != MBEDTLS_ERR_SSL_WANT_READ && ret != MBEDTLS_ERR_SSL_WANT_WRITE)
            {
                ESP_LOGE(TAG, "mbedtls_ssl_write returned -0x%x", -ret);
                goto exit;
            }
        }

        len = ret;
        ESP_LOGI(TAG, "%d bytes written", len);
        ESP_LOGI(TAG, "Reading HTTP response...");

        do
        {
            len = sizeof(buf) - 1;
            bzero(buf, sizeof(buf));
            ret = mbedtls_ssl_read(&ssl, (unsigned char *)buf, len);

            if(ret == MBEDTLS_ERR_SSL_WANT_READ || ret == MBEDTLS_ERR_SSL_WANT_WRITE)
                continue;

            if(ret == MBEDTLS_ERR_SSL_PEER_CLOSE_NOTIFY) {
                ret = 0;
                break;
            }

            if(ret < 0)
            {
                ESP_LOGE(TAG, "mbedtls_ssl_read returned -0x%x", -ret);
                break;
            }

            if(ret == 0)
            {
                ESP_LOGI(TAG, "connection closed");
                break;
            }

            len = ret;
            ESP_LOGI(TAG, "%d bytes read", len);
            /* Print response directly to stdout as it is read */
            for(int i = 0; i < len; i++) {
                putchar(buf[i]);
            }
        } while(1);

        mbedtls_ssl_close_notify(&ssl);

    exit:
        mbedtls_ssl_session_reset(&ssl);
        mbedtls_net_free(&server_fd);

        if(ret != 0)
        {
            mbedtls_strerror(ret, buf, 100);
            ESP_LOGE(TAG, "Last error was: -0x%x - %s", -ret, buf);
        }

        for(int countdown = 10; countdown >= 0; countdown--) {
            ESP_LOGI(TAG, "%d...", countdown);
            vTaskDelay(1000 / portTICK_PERIOD_MS);
        }
        ESP_LOGI(TAG, "Starting again!");
    }
}

void app_main()
{
    ESP_ERROR_CHECK( nvs_flash_init() );
    initialise_wifi();
    xTaskCreate(&https_get_task, "https_get_task", 8192, NULL, 5, NULL);
}

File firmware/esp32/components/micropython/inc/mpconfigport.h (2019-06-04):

// Options to control how MicroPython is built for this port,
// overriding defaults in py/mpconfig.h.

#include <stdint.h>
#include <alloca.h>
#include "rom/ets_sys.h"

// object representation and NLR handling
#define MICROPY_OBJ_REPR                    (MICROPY_OBJ_REPR_A)
#define MICROPY_NLR_SETJMP                  (1)

// memory allocation policies
#define MICROPY_ALLOC_PATH_MAX              (128)

// emitters
#define MICROPY_PERSISTENT_CODE_LOAD        (1)

// compiler configuration
#define MICROPY_COMP_MODULE_CONST           (1)
#define MICROPY_COMP_TRIPLE_TUPLE_ASSIGN    (1)

// optimisations
#define MICROPY_OPT_COMPUTED_GOTO           (1)
#define MICROPY_OPT_MPZ_BITWISE             (1)

// Python internal features
//#define MICROPY_READER_VFS                  (1)
#define MICROPY_READER_POSIX                (1)
#define MICROPY_ENABLE_GC                   (1)
#define MICROPY_ENABLE_FINALISER            (1)
#define MICROPY_STACK_CHECK                 (1)
#define MICROPY_ENABLE_EMERGENCY_EXCEPTION_BUF (1)
#define MICROPY_KBD_EXCEPTION               (1)
#define MICROPY_HELPER_REPL                 (1)
#define MICROPY_REPL_EMACS_KEYS             (1)
#define MICROPY_REPL_AUTO_INDENT            (1)
#define MICROPY_LONGINT_IMPL                (MICROPY_LONGINT_IMPL_MPZ)
#define MICROPY_ENABLE_SOURCE_LINE          (1)
#define MICROPY_ERROR_REPORTING             (MICROPY_ERROR_REPORTING_NORMAL)
#define MICROPY_WARNINGS                    (1)
#define MICROPY_FLOAT_IMPL                  (MICROPY_FLOAT_IMPL_FLOAT)
#define MICROPY_PY_BUILTINS_COMPLEX         (1)
#define MICROPY_CPYTHON_COMPAT              (1)
#define MICROPY_STREAMS_NON_BLOCK           (1)
#define MICROPY_STREAMS_POSIX_API           (0)
#define MICROPY_MODULE_BUILTIN_INIT         (1)
#define MICROPY_MODULE_WEAK_LINKS           (1)
#define MICROPY_MODULE_FROZEN_STR           (0)
#define MICROPY_MODULE_FROZEN_MPY           (1)
#define MICROPY_QSTR_EXTRA_POOL             mp_qstr_frozen_const_pool
#define MICROPY_CAN_OVERRIDE_BUILTINS       (1)
#define MICROPY_USE_INTERNAL_ERRNO          (0)
#define MICROPY_USE_INTERNAL_PRINTF         (0) // ESP32 SDK requires its own printf
#define MICROPY_ENABLE_SCHEDULER            (1)
#define MICROPY_SCHEDULER_DEPTH             (8)
//#define MICROPY_VFS                         (1)
//#define MICROPY_VFS_FAT                     (1)

// control over Python builtins
#define MICROPY_PY_FUNCTION_ATTRS           (1)
#define MICROPY_PY_STR_BYTES_CMP_WARN       (1)
#define MICROPY_PY_BUILTINS_STR_UNICODE     (1)
#define MICROPY_PY_BUILTINS_STR_CENTER      (1)
#define MICROPY_PY_BUILTINS_STR_PARTITION   (1)
#define MICROPY_PY_BUILTINS_STR_SPLITLINES  (1)
#define MICROPY_PY_BUILTINS_BYTEARRAY       (1)
#define MICROPY_PY_BUILTINS_MEMORYVIEW      (1)
#define MICROPY_PY_BUILTINS_SET             (1)
#define MICROPY_PY_BUILTINS_SLICE           (1)
#define MICROPY_PY_BUILTINS_SLICE_ATTRS     (1)
#define MICROPY_PY_BUILTINS_FROZENSET       (1)
#define MICROPY_PY_BUILTINS_PROPERTY        (1)
#define MICROPY_PY_BUILTINS_RANGE_ATTRS     (1)
#define MICROPY_PY_BUILTINS_TIMEOUTERROR    (1)
#define MICROPY_PY_ALL_SPECIAL_METHODS      (1)
#define MICROPY_PY_BUILTINS_COMPILE         (1)
#define MICROPY_PY_BUILTINS_ENUMERATE       (1)
#define MICROPY_PY_BUILTINS_EXECFILE        (1)
#define MICROPY_PY_BUILTINS_FILTER          (1)
#define MICROPY_PY_BUILTINS_REVERSED        (1)
#define MICROPY_PY_BUILTINS_NOTIMPLEMENTED  (1)
#define MICROPY_PY_BUILTINS_INPUT           (1)
#define MICROPY_PY_BUILTINS_MIN_MAX         (1)
#define MICROPY_PY_BUILTINS_POW3            (1)
#define MICROPY_PY_BUILTINS_HELP            (1)
#define MICROPY_PY_BUILTINS_HELP_TEXT       esp32_help_text
#define MICROPY_PY_BUILTINS_HELP_MODULES    (1)
#define MICROPY_PY___FILE__                 (1)
#define MICROPY_PY_MICROPYTHON_MEM_INFO     (1)
#define MICROPY_PY_ARRAY                    (1)
#define MICROPY_PY_ARRAY_SLICE_ASSIGN       (1)
#define MICROPY_PY_ATTRTUPLE                (1)
#define MICROPY_PY_COLLECTIONS              (1)
#define MICROPY_PY_COLLECTIONS_ORDEREDDICT  (1)
#define MICROPY_PY_MATH                     (1)
#define MICROPY_PY_MATH_SPECIAL_FUNCTIONS   (1)
#define MICROPY_PY_CMATH                    (1)
#define MICROPY_PY_GC                       (1)
#define MICROPY_PY_IO                       (1)
#define MICROPY_PY_IO_FILEIO                (1)
#define MICROPY_PY_IO_BYTESIO               (1)
#define MICROPY_PY_IO_BUFFEREDWRITER        (1)
#define MICROPY_PY_STRUCT                   (1)
#define MICROPY_PY_SYS                      (1)
#define MICROPY_PY_SYS_MAXSIZE              (1)
#define MICROPY_PY_SYS_MODULES              (1)
#define MICROPY_PY_SYS_EXIT                 (1)
#define MICROPY_PY_SYS_STDFILES             (1)
#define MICROPY_PY_SYS_STDIO_BUFFER         (1)
#define MICROPY_PY_UERRNO                   (1)
#define MICROPY_PY_USELECT                  (1)
#define MICROPY_PY_UTIME_MP_HAL             (1)
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

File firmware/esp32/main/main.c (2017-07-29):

#include "freertos/FreeRTOS.h"
#include "esp_wifi.h"
#include "esp_system.h"
#include "esp_event.h"
#include "esp_event_loop.h"
#include "esp_log.h"
#include "nvs_flash.h"
#include "driver/gpio.h"
#include "driver/touch_pad.h"
#include "soc/rtc_cntl_reg.h"
#include "soc/rtc_io_reg.h"
#include "soc/sens_reg.h"

#include "board.h"
#include "sdkconfig.h"

#include "audio.h"
#include "events.h"
#include "ble.h"
#include "i2c.h"
#include "leds.h"
#include "display.h"
#include "vgm.h"
#include "touch.h"
#include "sdcard.h"
#include "misc.h"

#include "apps/sntp/sntp.h"

static const char* TAG = "CPV2017";

esp_err_t event_handler(void *ctx, system_event_t *event)
{
    return ESP_OK;
}

extern void python_start(void);

void app_main(void)
{
	ESP_LOGI(TAG, "Booting the ESP32 / CPV 2017 Badge...");

	ESP_LOGI(TAG, "Initializing display...");
    display_init();
    //display_show_logo();

    // Initialize everything else
    ESP_LOGI(TAG, "Initializing nvs...");
    nvs_flash_init();
    update_nvs_version_info();

    ESP_LOGI(TAG, "Initializing event queue...");
    eventq_init();

    ESP_LOGI(TAG, "Initializing I2C...");
	i2c_init();
	i2c_config_accel();

    ESP_LOGI(TAG, "Initializing TCP/IP...");
    tcpip_adapter_init();

    ESP_LOGI(TAG, "Initializing event loop...");
    ESP_ERROR_CHECK(esp_event_loop_init(event_handler, NULL));

    ESP_LOGI(TAG, "Initializing SD card...");
    sdcard_init();

    ESP_LOGI(TAG, "OS heap free is currently %d bytes", xPortGetFreeHeapSize());

    ESP_LOGI(TAG, "Initializing touch...");
    tp_init();

    ESP_LOGI(TAG, "Initializing BLE...");
    ble_init();

    ESP_LOGI(TAG, "OS heap free is currently %d bytes", xPortGetFreeHeapSize());

    ESP_LOGI(TAG, "Initializing WiFi...");
    wifi_init_config_t cfg = WIFI_INIT_CONFIG_DEFAULT();
    ESP_ERROR_CHECK( esp_wifi_init(&cfg) );
    ESP_ERROR_CHECK( esp_wifi_set_storage(WIFI_STORAGE_RAM) );
    ESP_ERROR_CHECK( esp_wifi_set_mode(WIFI_MODE_STA) );
    wifi_config_t sta_config = {
        .sta = {
            .ssid = CONFIG_WIFI_SSID,
            .password = CONFIG_WIFI_PASSWORD,
        	.bssid_set = false
        }
    };

    ESP_LOGI(TAG, "OS heap free is currently %d bytes", xPortGetFreeHeapSize());

    ESP_ERROR_CHECK( esp_wifi_set_config(WIFI_IF_STA, &sta_config) );
    ESP_ERROR_CHECK( esp_wifi_start() );
    ESP_LOGI(TAG, "OS heap free is currently %d bytes", xPortGetFreeHeapSize());
    ESP_ERROR_CHECK( esp_wifi_set_auto_connect(true) );
    ESP_ERROR_CHECK( esp_wifi_connect() );

    ESP_LOGI(TAG, "OS heap free is currently %d bytes", xPortGetFreeHeapSize());

    ESP_LOGI(TAG, "Initializing SNTP...");
    sntp_setoperatingmode(SNTP_OPMODE_POLL);
    sntp_setservername(0, "pool.ntp.org");
    sntp_init();

    ESP_LOGI(TAG, "OS heap free is currently %d bytes", xPortGetFreeHeapSize());
    audio_init();
    led_init_udp();

    ESP_LOGI(TAG, "Done initializing!");
    ESP_LOGI(TAG, "OS heap free is currently %d bytes", xPortGetFreeHeapSize());
    python_start();

    while (1) {
    	vTaskDelay(1000 / portTICK_PERIOD_MS);
    }
}

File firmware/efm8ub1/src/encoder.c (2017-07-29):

#include <SI_EFM8UB1_Register_Enums.h>
#include "board.h"
#include "efm8_usb.h"

int8_t encoderCount = 0;
uint8_t internalEncoderStatus = 0;
uint8_t i2cEncoderStatus = 0;
uint8_t hidEncoderStatus = 0;

static uint8_t prevAB;
static uint8_t prevA;
static uint8_t prevB;
static uint8_t prevSW = 0x7f;

void encoder_enterBootloader() {
	USBD_Stop();
	// Write R0 and issue a software reset
	SFRPAGE = 0;
	*((uint8_t SI_SEG_DATA *)0x00) = 0xA5;
	RSTSRC = RSTSRC_SWRSF__SET | RSTSRC_PORSF__SET;
}

void encoder_init()
{
	// If the encoder switch is pushed down on powerup, reset into bootloader
	if (!ENC_SW) {
		encoder_enterBootloader();
	}

	// TODO(supersat): Figure out why these are not initialized on reset automatically
	encoderCount = 0;
	internalEncoderStatus = 0;
	i2cEncoderStatus = 0;
	hidEncoderStatus = 0;

	prevA = ENC_A ? 0xff : 0x00;
	prevB = ENC_B ? 0xff : 0x00;
	prevAB = (prevB & 0xAA) | (prevA & 0x55);
	prevSW = 0x7f;
}

void encoder_updateStatus()
{
	encoder_updateInternalStatus();
	IE_EA = 0;
	encoder_updateExternalStatus(&i2cEncoderStatus);
	encoder_updateExternalStatus(&hidEncoderStatus);
	IE_EA = 1;
}

// Loosely based on code by Oleg Mazurov
// returns non-zero when the encoder status changes
void encoder_updateInternalStatus()
{
	SI_SEGMENT_VARIABLE(statusDecoder[], static const int8_t, SI_SEG_CODE) =
		{ 0, 1, -1, 0, -1, 0, 0, 1, 1, 0, 0, -1, 0, -1, 1, 0 };
	uint8_t result;
	// Debounce the push button
	prevSW = (prevSW & 0x80) | ((prevSW << 1) & 0x7e) | ENC_SW;
	if (prevSW & 0x80) {
		if ((prevSW & 0x7f) == 0x7f) {
			prevSW &= ~0x80;
			result = ENCODER_UP;
		} else {
			result = ENCODER_PRESSED;
		}
	} else {
		if ((prevSW & 0x7f) == 0) {
			prevSW |= 0x80;
			result = ENCODER_DOWN | ENCODER_PRESSED;
		} else {
			result = 0;
		}
	}

	prevA = (prevA << 1) | ENC_A;
	prevB = (prevB << 1) | ENC_B;
	// Debounce the A and B switches, and only update the encoder status when stable
	if ((prevA == 0x00 || prevA == 0xff) && (prevB == 0x00 || prevB == 0xff)) {
		prevAB = (prevAB << 2) | (prevB & 2) | (prevA & 1);
		encoderCount += statusDecoder[prevAB & 0xf];
		if (encoderCount == -4) {
			encoderCount = 0;
			result |= ENCODER_CCW;
		} else if (encoderCount == 4) {
			encoderCount = 0;
			result |= ENCODER_CW;
		}
	}

	internalEncoderStatus = result;
}

void encoder_updateExternalStatus(uint8_t *status)
{
	uint8_t prevStatus = *status;

	if (internalEncoderStatus & ENCODER_CW) {
		if (*status & ENCODER_CCW) {
			*status &= ~ENCODER_CCW;
		} else {
			*status |= ENCODER_CW;
		}
	}

	if (internalEncoderStatus & ENCODER_CCW) {
		if (*status & ENCODER_CW) {
			*status &= ~ENCODER_CW;
		} else {
			*status |= ENCODER_CCW;
		}
	}

	if (internalEncoderStatus & ENCODER_DOWN) {
		if (*status & ENCODER_UP) {
			*status &= ~ENCODER_UP;
		} else {
			*status |= ENCODER_DOWN;
		}
	}

	if (internalEncoderStatus & ENCODER_UP) {
		if (*status & ENCODER_DOWN) {
			*status &= ~ENCODER_DOWN;
		} else {
			*status |= ENCODER_UP;
		}
	}

	if (!(*status & ENCODER_DIRTY)) {
		if (!(internalEncoderStatus & ENCODER_CW)) {
			*status &= ~ENCODER_CW;
		}

		if (!(internalEncoderStatus & ENCODER_CCW)) {
			*status &= ~ENCODER_CCW;
		}

		if (!(internalEncoderStatus & ENCODER_DOWN)) {
			*status &= ~ENCODER_DOWN;
		}

		if (!(internalEncoderStatus & ENCODER_UP)) {
			*status &= ~ENCODER_UP;
		}

		if (internalEncoderStatus & ENCODER_PRESSED) {
			*status |= ENCODER_PRESSED;
		} else {
			*status &= ~ENCODER_PRESSED;
		}
	}

	if (prevStatus != *status) {
		*status |= ENCODER_DIRTY;
	}
}

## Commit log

2017-07-29 Initial commit of the CPV2017 badge
    [BOM.xlsx, LEDs.sch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]
2019-05-06 Switch protocols from git to https for getting the micropython submodule
2019-06-03 Micropython glue updates
2019-06-04 Add support for polling EFM8 power status
2021-01-20 Update BOM
    [BOM.xlsx]
